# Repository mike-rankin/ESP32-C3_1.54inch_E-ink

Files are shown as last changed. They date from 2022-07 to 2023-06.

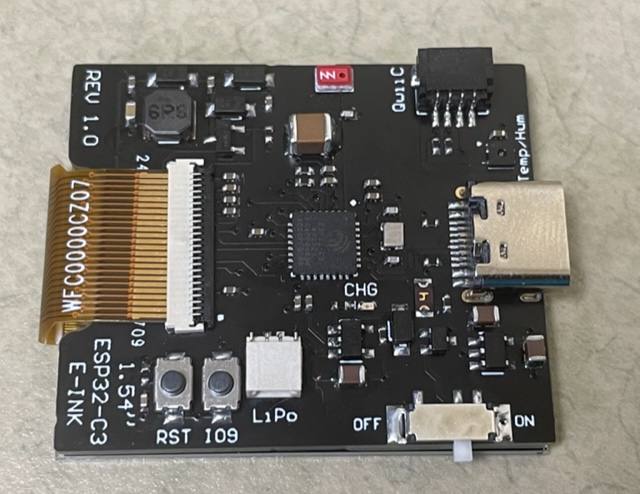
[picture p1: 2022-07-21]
Images/Component_Side_Rev1.jpg

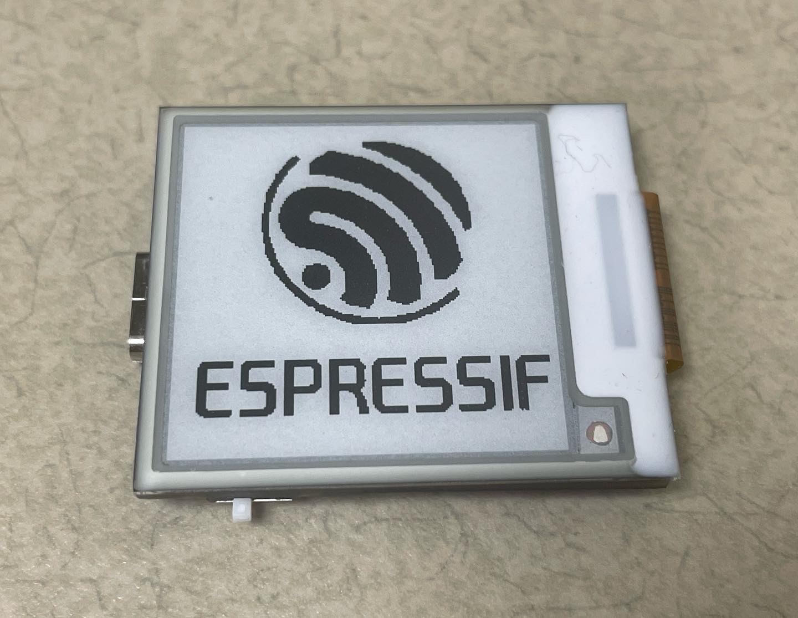
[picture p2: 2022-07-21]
Images/Display_Side_Rev1.jpg

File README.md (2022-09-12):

# ESP32-C3_1.54inch_E-ink
ESP32-C3 1.54inch E-ink Project

sensors
Component_Side_Rev1
Display_Side_Rev1

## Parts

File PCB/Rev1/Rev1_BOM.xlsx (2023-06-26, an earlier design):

Designator | Quantity | Vendor | Description | Part_Number | Manufacturer | Value
A1 | 1 | Digi-Key | Antenna Chip 2.4Gig | NN02-101 | Ignion | Chip Antenna
C1, C2, C5, C6, C8, C9, C12, C13, C14, C18, C20 | 11 |  | CAP 1uF 0402 |  |  | 1uF
C3, C4, C22 | 3 |  | CAP 10uF 0805 |  |  | 10uF
C7 | 1 |  | CAP 2.2uF 0603 |  |  | 2.2uF
C10, C11 | 2 |  | CAP 15pF 0402 |  |  | 15pF
C15, C19, C21, C23, C24, C25 | 6 |  | CAP 0.1uF 0402 |  |  | 0.1uF
C16 | 1 |  | CAP 1pF 0402 |  |  | 1pF
C17 | 1 |  | CAP 47uF 1210 |  |  | 47uF
D1 | 1 | LCSC | DIODE SCHOTTKY 20V 500MA SOD-123 | C78746 | Micro | MBR0520
D2, D3, D4 | 3 | LCSC | DIODE SCHOTTKY 20V 500MA SOD-123 | C78746 | Micro | MBR0520
D5 | 1 | LCSC | LED Red 0402 | C364556 | Lite-On | Red Led
F1 | 1 | LCSC | PTC FUSE 500mA hold, 1A trip | C261942 | TLC | TLC-PSMD050
H1 | 1 | Digi-Key | CONN HEADER 4POS .100 R/A QWIIC | PRT-14417 | JST | QWiiC
J1 | 1 | LCSC | CONN RECPT USB-C | C165948 | KHE | USB-C
J2 | 1 | Digi-Key | CONN FFC TOP/BOT 24POS 0.50MM R/A | 687124182122 | Wurth | 24POS Flex Connector
L1 | 1 | LCSC | INDUCTOR 68uH 20% 4mmx4mm | C135265 | SXN | 68uH
Q1 | 1 | LCSC | MOSFET P-CH 20V 1.4A SC-70 | C172434 | LRC | LP1480WT1G
Q2 | 1 | LCSC | MOSFET N-CH 60V 300MA SOT-23 | 2N7002K-T1-E3 | Vishay Siliconix
R1, R3 | 2 |  | RES 5.1K 0402 |  |  | 5.1K
R2, R5, R6 | 3 |  | RES 100K 0402 |  |  | 100K
R4 | 1 |  | RES 2.2R 0402 |  |  | 2.2R
R7, R8, R9 | 3 |  | RES 10K 0402 |  |  | 10K
R10 | 1 |  | RES 4.7K 0402 |  |  | 4.7K
R11 | 1 |  | RES 4K 0402 |  |  | 4K
S1 | 1 | LCSC | SWITCH SLIDE SMD | K3-1296S-E1 | Korean Hroparts Elec | SWITCH SLIDE
S2, S3 | 2 | LCSC | Tactile Micro Switch | C455281 | XUNPU
U1 | 1 | LCSC | IC LDO 3.3V 0.5A SOT23-5 | C164106 | Holtek | HT7833
U2 | 1 | LCSC | WIFI/Bluetooth, VFQFN-32 | C2848860 | Espressif | ESP32-C3FN4
U3 | 1 | Digi-Key | Charger IC Lithium-Ion/Polymer SOT23-5 | MCP73831T-2ACI/OT | Microchip | MCP73831T-2ACI
U4 | 1 | LCSC | Humidity/Temperature Sensor | SHTC3 | Sensirion | Temp/Humid
X1 | 1 | Digi-Key | CRYSTAL 40MHZ 10PF SMD | ECS-400-10-37B2-CKM | ECS | 40 Mhz

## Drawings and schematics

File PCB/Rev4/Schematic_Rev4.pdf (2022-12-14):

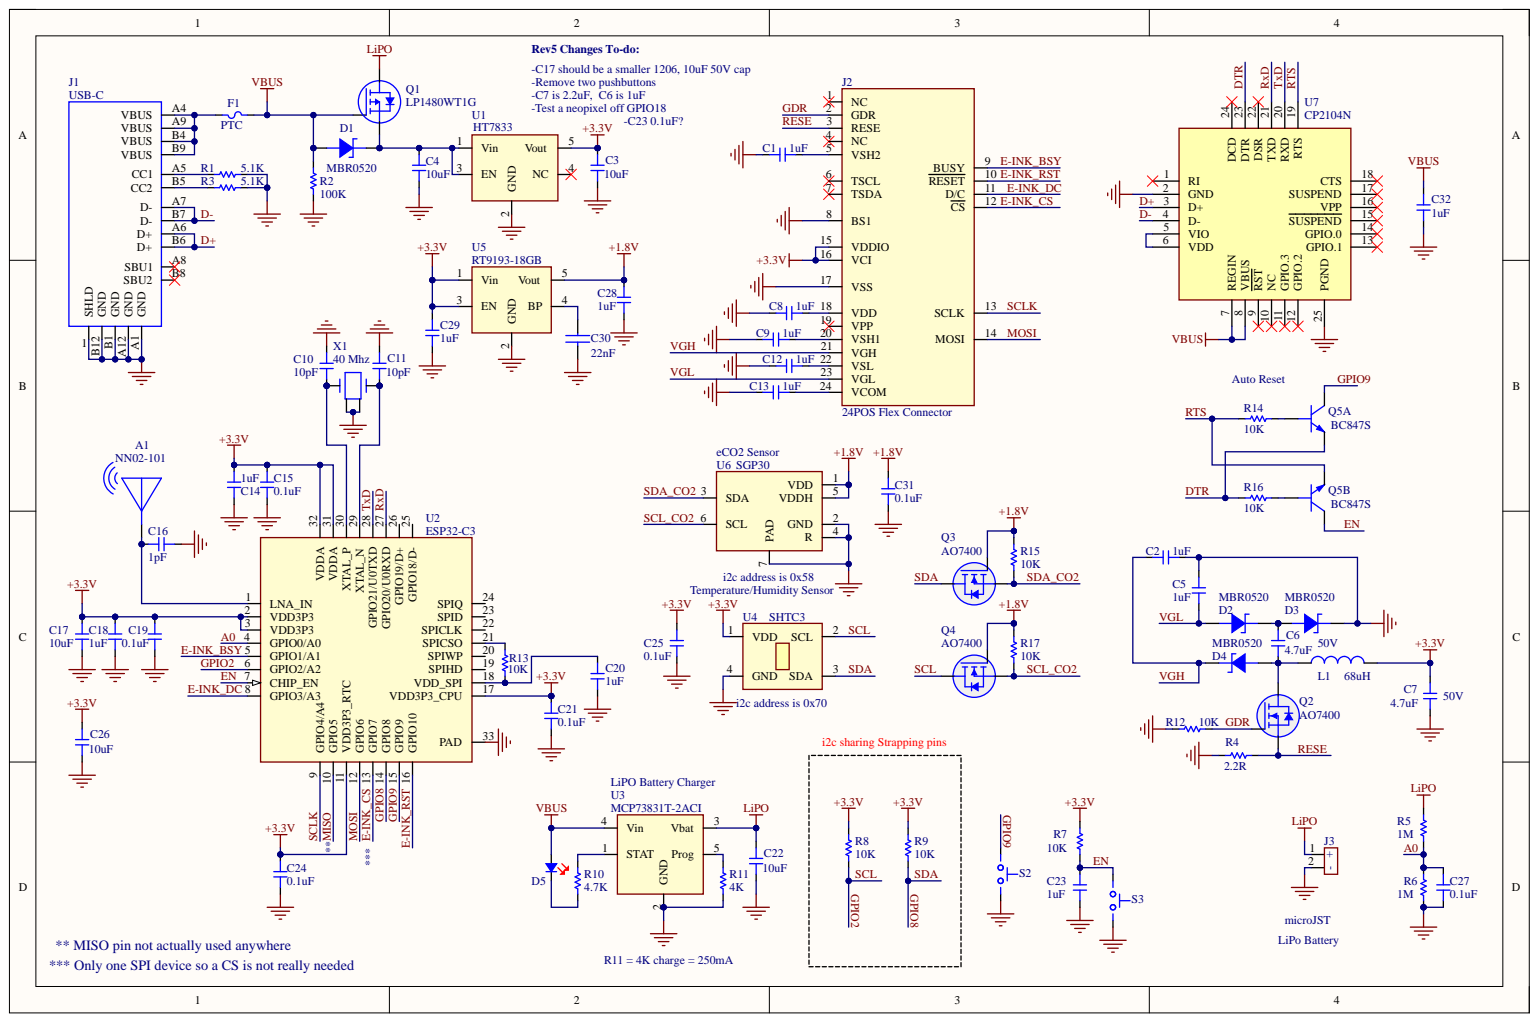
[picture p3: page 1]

Rev5 Changes To-do:
-C17 should be a smaller 1206, 10uF 50V cap
-Remove two pushbuttons
-Test a neopixel off GPIO18

RTS 19 RXD 20 TXD 21 DSR 22 DTR 23

C5 1uF VG L | MBR0520 MBR0520 D2 D3

VDD GND | SCL

*** Only one SPI device so a CS is not really needed **

** MISO pin not actually used anywhere

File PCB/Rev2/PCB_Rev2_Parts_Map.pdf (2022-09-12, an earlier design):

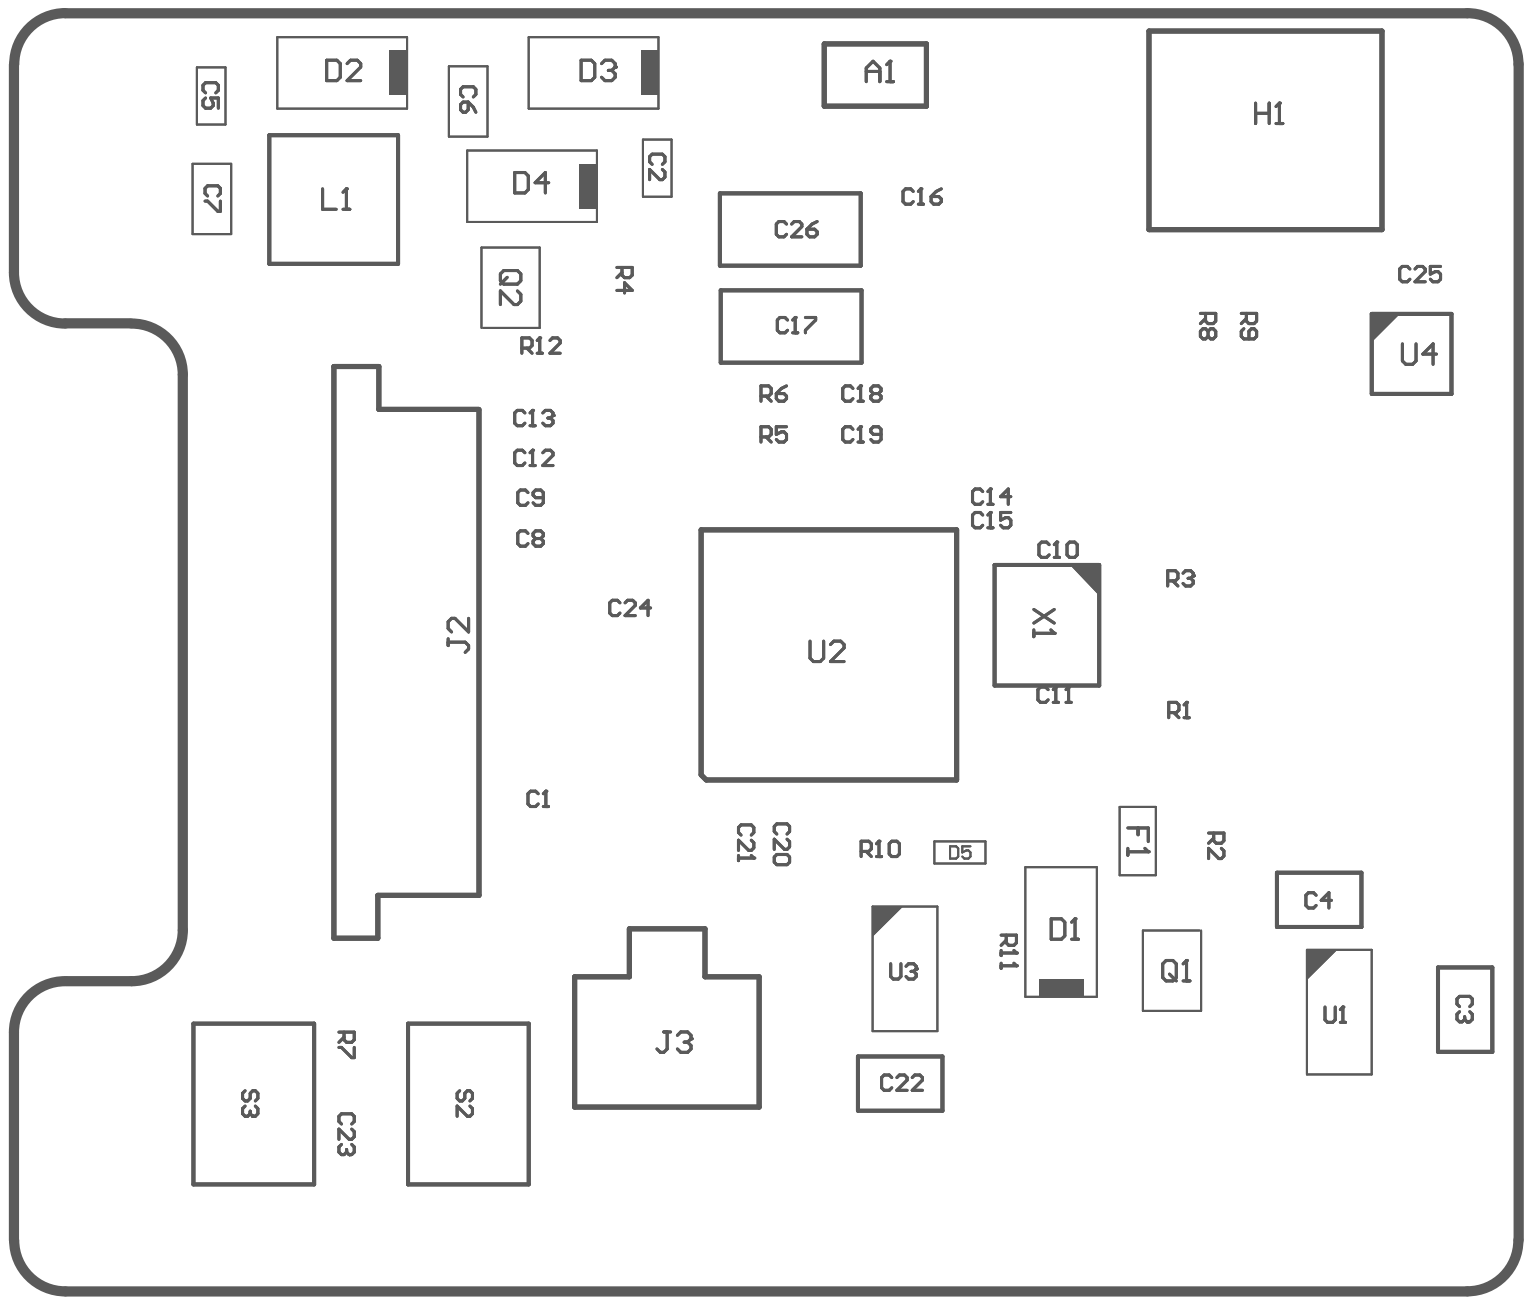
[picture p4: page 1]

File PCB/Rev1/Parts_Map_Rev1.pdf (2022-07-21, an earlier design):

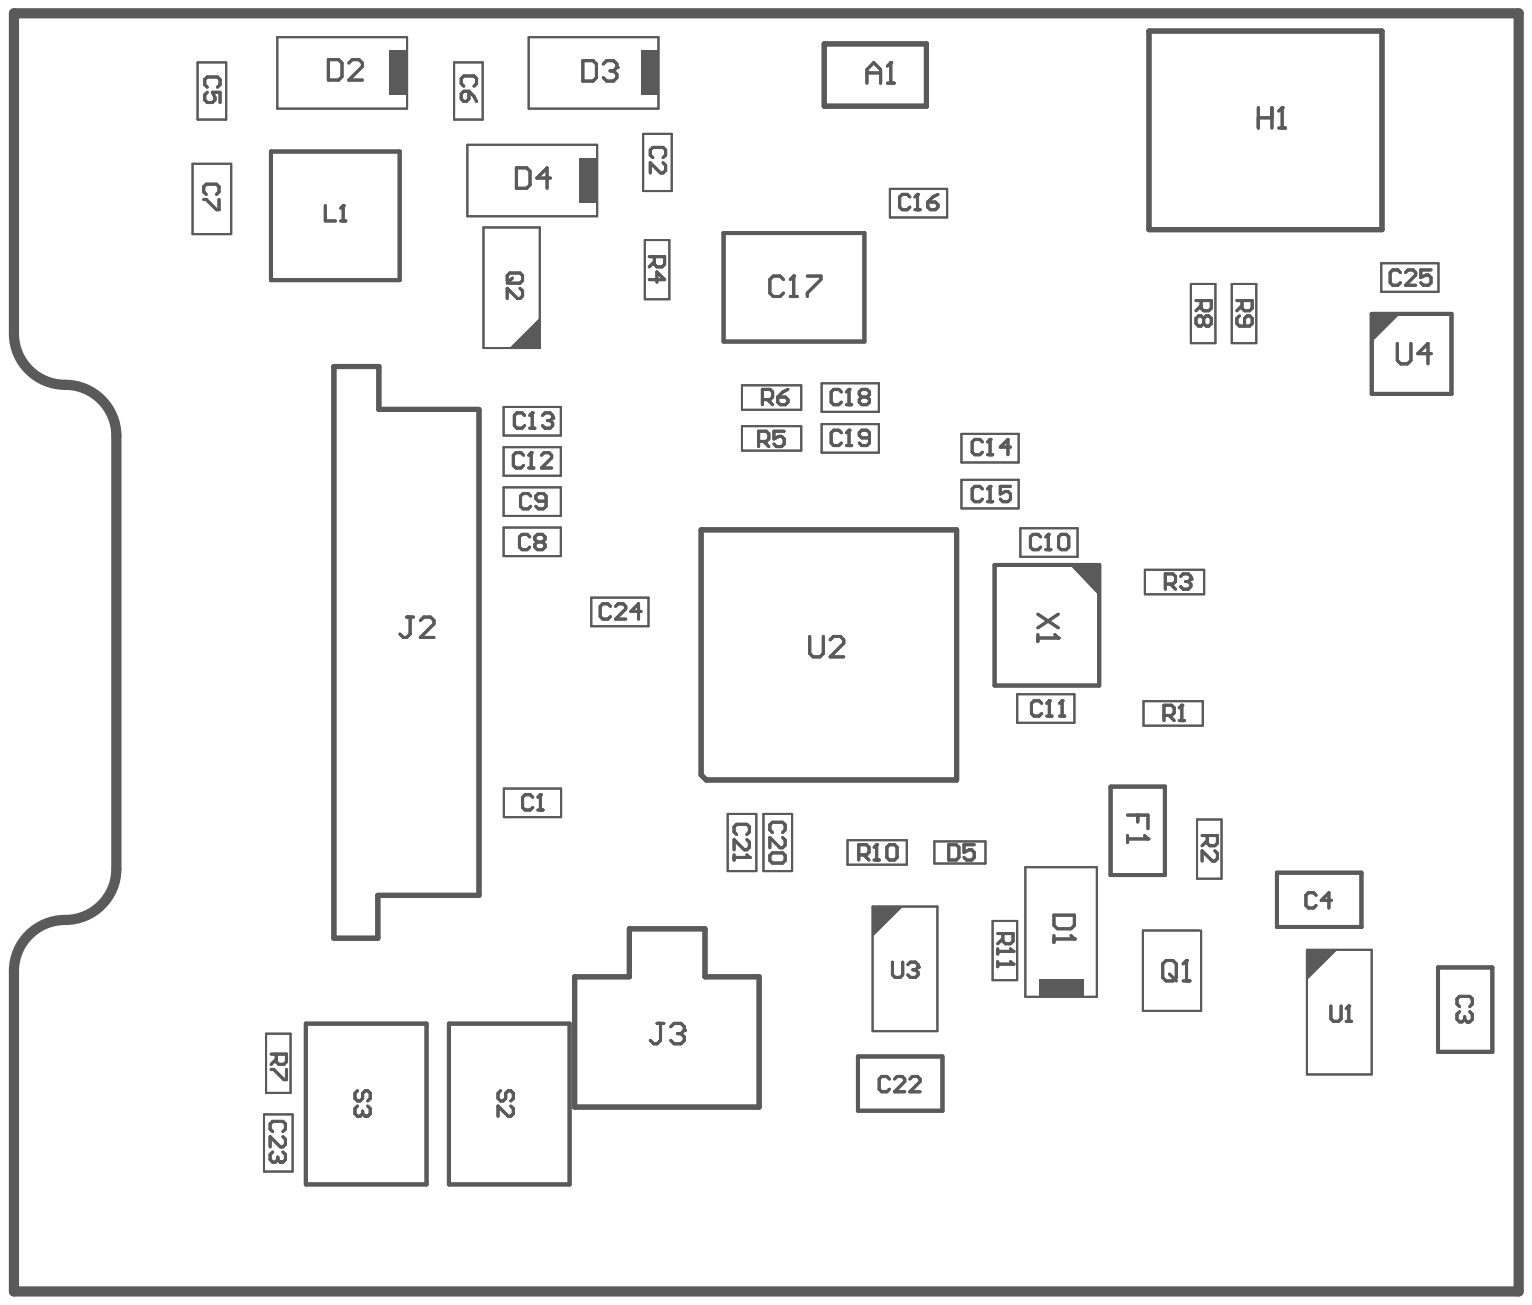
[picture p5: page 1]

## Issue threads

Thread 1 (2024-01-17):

Power consumption

BatsIhor, 2024-01-17:
Hi Mike,

Not an issue just a question, what is power consumption during deep sleep?

Thanks
Ihor

mike-rankin, 2024-01-18:
It's been a while since I've worked on this project but on a newer board I'm working on, current draw of the C3 in deep sleep is around 20uA.

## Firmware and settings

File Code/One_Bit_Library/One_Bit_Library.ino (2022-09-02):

//
// OneBitDisplay EPD (e-ink) demo sketch
// Written by Larry Bank 7/10/2022
//
// This program shows how to use epd panels
// with the OneBitDisplay library. The general idea
// is that it doesn't support "immediate" mode with e-ink. 
// You'll need to allocate a buffer to hold the pixel
// data, draw on it, then dump it all at once to the panel
// as a full update (display) or partial (displayPartial).
// This demo draws some text using the built-in fonts and
// a custom font in Adafruit_GFX format
//
// The target hardware for this demo is the Pimoroni Badger2040
// A RPI Pico MCU with a UC8151 2.9" 128x296 1-bpp epd
//
#include <OneBitDisplay.h>
#include "Roboto_Black_40.h"

ONE_BIT_DISPLAY lcd;

#define BADGER_FREQ 12000000  //Was 12000000
#define BADGER_CS 7
#define BADGER_BUSY 1
#define BADGER_RES 10
#define BADGER_DC 3
#define BADGER_MOSI 6
#define BADGER_SCK 4
#define BADGER_BATT 0

void setup() 
{
  // Initialize the library by telling it how the display is connected
  lcd.setSPIPins(BADGER_CS, BADGER_MOSI, BADGER_SCK, BADGER_DC, BADGER_RES, BADGER_BUSY);
  lcd.SPIbegin(EPD42R_400x300, BADGER_FREQ);

  // Set the orientation to draw in the direction we want
  lcd.setRotation(0); // the panel is actually 128 wide by 296 tall, but oriented 90 right
  lcd.allocBuffer(); // allocate a back buffer and keep it internal to the class
  lcd.fillScreen(0); // 0 for EPDs is white (for OneBitDisplay)
  lcd.setFont(FONT_12x16); // use the internal stretched/smoothed font
  lcd.setCursor(10,10);
  lcd.print("This was a full update");
  lcd.display(); // do a full update
  for (int i=24; i<120; i += 32) {
    lcd.fillCircle(i, i, 8, 1);
    lcd.displayPartial(); // draw a ball and show intermediate results with a partial update
  }
  lcd.setCursor(10, 10);
    //lcd.print("then a partial update");
    //lcd.displayPartial(); // final partial update
  delay(4000);
  lcd.fillScreen(0);
  lcd.setTextColor(OBD_RED);
  lcd.setFreeFont(&Roboto_Black_40);
  lcd.setCursor(0,40);
  lcd.println("Love");
  lcd.println("the red");
  lcd.setFont(FONT_12x16);
  lcd.setCursor(0,112);
  lcd.println("Finished");
  lcd.display(); // show final screen with a full update
}

void loop() {
 // nothing going on here
}

/*
obdDrawLine(&obd, x, 0, OLED_WIDTH-x, OLED_HEIGHT-1, 1, 1);


ulTime = micros() - ulTime;
  obdFill(&obd, 0, 1);
  obdWriteString(&obd, 0, 0, 0, (char *)"100 frames drawn", FONT_8x8, 0, 1);
  sprintf(szTemp, "in %d ms", (int)(ulTime/1000));


 sprintf(szTemp, "%d bytes generated", obdGetCommandLen(&obdCMD));
  obdWriteString(&obd, 0,0,2, szTemp, FONT_6x8, 0, 1);
  delay(4000);
  obdExecCommands(ucBuffer, obdGetCommandLen(&obdCMD), &obd, 0);
  obdDumpBuffer(&obd, NULL);


char szTemp[32];
unsigned long ms;

obdFill(&obd, 0, 0);
ms = micros();
obdWriteStringCustom(&obd, (GFXfont *)&FreeSerif12pt7b, 0, 16, (char *)"Hello World",1);
obdWriteStringCustom(&obd, (GFXfont *)&FreeSerif12pt7b, 0, 16+FreeSerif12pt7b.yAdvance, (char *)"Fast Perf!", 1);
ms = micros() - ms;
obdDumpBuffer(&obd, NULL);
sprintf(szTemp, "rendered in %d us", (int)ms);
obdWriteString(&obd, 0,0,7,szTemp, FONT_6x8, 0, 1);
delay(4000);
*/

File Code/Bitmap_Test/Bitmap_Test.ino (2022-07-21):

//https://www.youtube.com/watch?v=CMNuMOcvpFM
//https://javl.github.io/image2cpp/


//Solution: Keep Serial Monitor closed while programming. 
//Serial Monitor. Serial output works as expected.




#include <Arduino.h>
#include <Wire.h>

// GxEPD2_HelloWorld.ino by Jean-Marc Zingg

// see GxEPD2_wiring_examples.h for wiring suggestions and examples
// if you use a different wiring, you need to adapt the constructor parameters!

// uncomment next line to use class GFX of library GFX_Root instead of Adafruit_GFX
//#include <GFX.h>

#define SPI_EPD_CLK     4
#define SPI_EPD_MOSI    6
#define SPI_EPD_MISO    5
#define SPI_EPD_CS      7
#define SPI_EPD_BUSY    1
#define SPI_EPD_RST     10
#define SPI_EPD_DC      3

#include <GxEPD2_BW.h>
#include <GxEPD2_3C.h>
#include <Fonts/FreeMonoBold9pt7b.h>
#include "Bitmaps.h"

// select the display class and display driver class in the following file (new style):
#include "GxEPD2_display_selection_new_style.h"

// or select the display constructor line in one of the following files (old style):
// #include "GxEPD2_display_selection.h"
// #include "GxEPD2_display_selection_added.h"

// alternately you can copy the constructor from GxEPD2_display_selection.h or GxEPD2_display_selection_added.h to here
// e.g. for Wemos D1 mini:
//GxEPD2_BW<GxEPD2_154_D67, GxEPD2_154_D67::HEIGHT> display(GxEPD2_154_D67(/*CS=D8*/ SS, /*DC=D3*/ 0, /*RST=D4*/ 2, /*BUSY=D2*/ 4)); // GDEH0154D67



const char HelloWorld[] = "TEST";

void helloWorld()
{
  
  
}


void setup()
{
  Serial.begin(115200);
  SPI.end(); // release standard SPI pins, e.g. SCK(18), MISO(19), MOSI(23), SS(5)
  SPI.begin(SPI_EPD_CLK, SPI_EPD_MISO, SPI_EPD_MOSI, SPI_EPD_CS); // map and init SPI pins SCK(13), MISO(12), MOSI(14), SS(15)
  display.init();
  display.setRotation(1);
  //display.setFont(&FreeMonoBold9pt7b);
  //display.setTextColor(GxEPD_BLACK);

  //helloWorld();
  drawBitmaps(ACROBOTIC_LOGO);

  // display.hibernate();
}



const char HelloEpaper[] = "ESP32-C3 eInk!";

void loop() 
{
  /*
  Serial.println("Testing");
  display.setRotation(2);
  display.setFont(&FreeMonoBold9pt7b);
  display.setTextColor(GxEPD_BLACK);
  int16_t tbx, tby; uint16_t tbw, tbh;
  // align with centered HelloWorld
  display.getTextBounds(HelloWorld, 0, 0, &tbx, &tby, &tbw, &tbh);
  uint16_t x = ((display.width() - tbw) / 2) - tbx;
  // height might be different
  display.getTextBounds(HelloEpaper, 0, 0, &tbx, &tby, &tbw, &tbh);
  uint16_t y = (display.height() * 3 / 4) + tbh / 2; // y is base line!
  // make the window big enough to cover (overwrite) descenders of previous text
  uint16_t wh = FreeMonoBold9pt7b.yAdvance;
  uint16_t wy = (display.height() * 3 / 4) - wh / 2;
  // full window mode is the initial mode, set it anyway
  display.setFullWindow();
  // DO NOT display.fillScreen(GxEPD_WHITE); keep current content!
  // display.fillRect(0, wy, display.width(), wh, GxEPD_WHITE); // clear rect instead
  display.fillScreen(GxEPD_WHITE);
  display.setCursor(random(0,30), random(20,display.height()));
  display.print(HelloEpaper);
  display.display();
  delay(5000);
  */
}



void drawBitmaps(const unsigned char *bitmap) 
{
  // Configure the display according to our preferences
  //display.setRotation(0);
  display.setFullWindow();
  // Display the bitmap image
  display.firstPage();
  do {
    display.fillScreen(GxEPD_WHITE);
    display.drawInvertedBitmap(0, 0, bitmap, display.epd2.WIDTH, display.epd2.HEIGHT, GxEPD_BLACK);
  } while(display.nextPage());
}

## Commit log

2022-07-07 Added schematic
2022-07-21 Updated all files
    [PCB_Project.PrjPcb, PCB_Rev1.PcbDoc, Rev1_BOM.xlsx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]
2022-09-12 Added Rev2 files
    [BOM_Rev2.xlsx, PCB_Project.PrjPcb, PCB_Rev1.PcbDoc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]
2022-12-14 added Rev4 schematic
2023-06-26 Delete Rev1_BOM.xlsx
    Made updates
    [Rev1_BOM.xlsx]
2023-06-26 Add files via upload
    Updated parts list
    [Rev1_BOM.xlsx]
